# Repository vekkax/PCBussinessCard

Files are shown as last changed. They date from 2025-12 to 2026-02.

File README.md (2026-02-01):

# PCB Business Card

The **PCB Business Card** is a hardware project inspired by the [Hackaday 2024 Business Card Contest](https://hackaday.io/contest/195949-2024-business-card-contest)   and the business cards created by [Salvaged Circuitry](https://www.youtube.com/watch?v=rEdWV4Augfc).

It is a compact and creative way to showcase your capabilities as a hardware designer while sharing your contact details. Beyond being a novelty, the card also functions as a (slightly impractical, but fun) development platform.

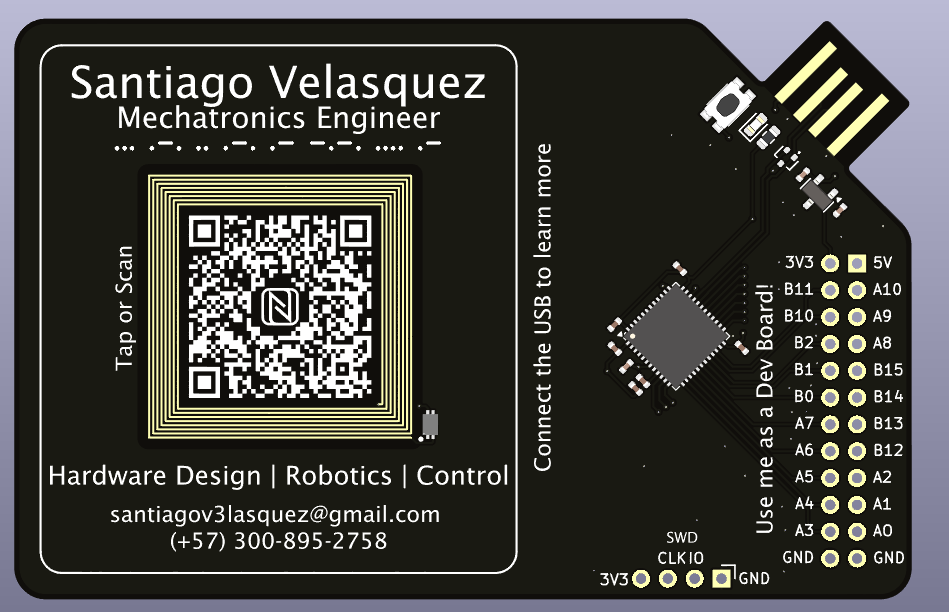
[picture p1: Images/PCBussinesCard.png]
PCB Business Card


---

## Board Design

The PCB was designed using **KiCad**, along with plugins such as **KiKit** and the **Fabrication Toolkit** to generate production-ready files.

The board features:

- **[STM32L452CEU](Datasheets/stm32l452ce.pdf)** microcontroller  
- **[NT2H1311F0DTLH](Datasheets/NTAG213F_216F.pdf)** NFC tag  
- Integrated **PCB USB connector**  
- Optional **pin headers**, allowing the card to be used as a development board  

The USB connector supplies power to the microcontroller through a **[3.3 V LDO regulator](Datasheets/LM3480.pdf)** and includes ESD protection on the data lines using a **TVS diode**. A power LED is placed next to the connector for visual feedback.

The NFC tag is connected to a custom PCB antenna designed using NXP’s [NFC Antenna Design Tool](https://community.nxp.com/t5/NFC/bd-p/nfc).  
This tool provides a convenient interface to design PCB NFC antennas (especially for NXP tags/readers) based on user-defined constraints. ST also provides a similar [antenna design tool](https://eds.st.com/antenna/#/).

---

### Bill of Materials (BOM)

| Reference | Value | Footprint | Quantity |
|---|---|---|---|
| C1–C4, C7–C9 | 100 nF | 0402 | 7 |
| C5 | 10 nF | 0402 | 1 |
| C6 | 1 µF | 0402 | 1 |
| D1 | RCLAMP0582B | SOT-416 | 1 |
| D2 | LED | 0603 | 1 |
| IC1 | NT2H1311F0DTL | SOT1312AB2 | 1 |
| R1 | 120 Ω | 0603 | 1 |
| SW1 | SMD push button | 4.6×1.8×1.9 mm | 1 |
| U1 | STM32L452CEU | QFN-48 | 1 |
| U2 | LM3480-3.3 | SOT-23 | 1 |

> **Note**  
> Reference designators were removed from the PCB layout to improve the visual appearance of the board.

---

## Fabrication

For fabrication, **KiCad’s KiKit** and **JLCPCB’s Fabrication Toolkit** plugins were used.

### Panelization

KiKit was used to panelize the PCB. Each panel contains **four PCB business cards**, separated by mouse bites and surrounded by left and right rails.

The panel configuration file can be found here:  
`PCBussinesCard_Circuit/Panels/panel_config.json`

For more information on KiKit panelization, refer to the official documentation:  
https://yaqwsx.github.io/KiKit/latest/panelization/examples/

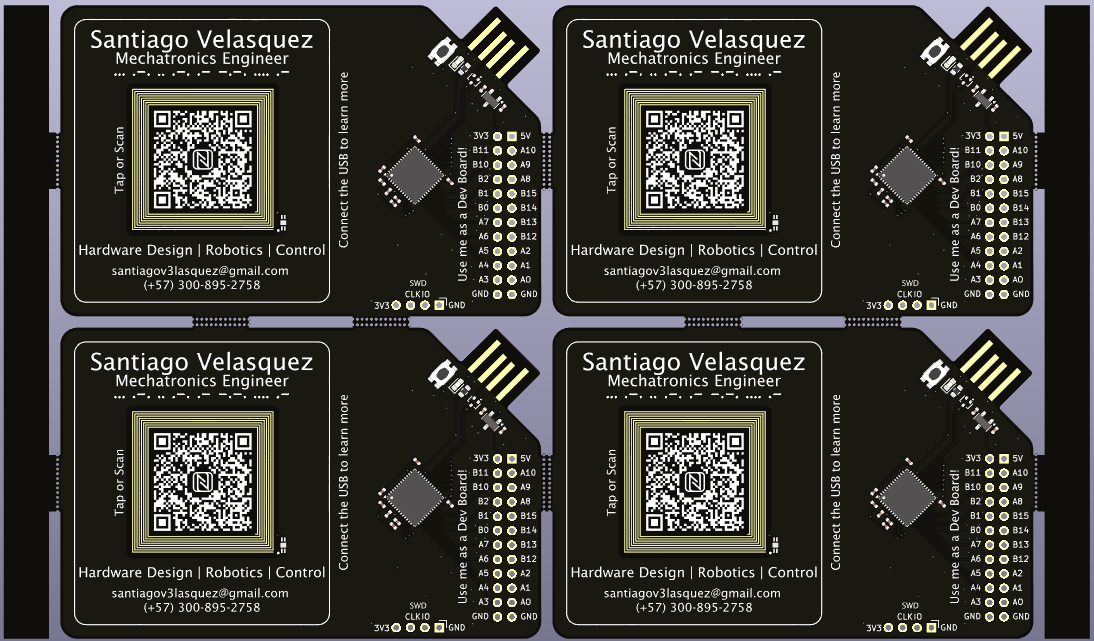
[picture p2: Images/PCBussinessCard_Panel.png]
Panelized Board


### Manufacturing

Manufacturing was done using **JLCPCB**, with production files generated via the JLCPCB Fabrication Toolkit plugin.

---

## Software

The USB connector is used to expose the board as a **USB Mass Storage Device**, allowing a host computer to read and write files (for example, a digital CV) directly to the microcontroller’s internal flash memory.

This implementation uses the STM32’s built-in **USB Full-Speed device** support and the **Mass Storage Class (MSC)**.

The implementation was based on and adapted from the following guide:  
[STM32 USB MSC using Flash Memory – Embetronicx](https://embetronicx.com/tutorials/microcontrollers/stm32/stm32-usb-device-msc-using-flash-memory/)

---

### Flash Memory Configuration

According to the [RM0394 Reference Manual](Datasheets/rm0394-stm32l41xxx42xxx43xxx44xxx45xxx46xxx-advanced-armbased-32bit-mcus-stmicroelectronics.pdf), the STM32L452 has **512 KB of flash memory** organized in a single bank.

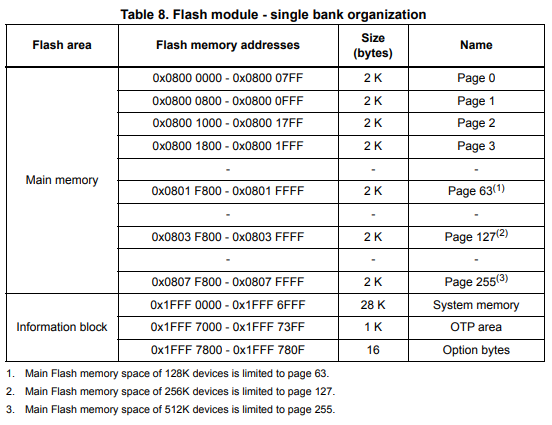
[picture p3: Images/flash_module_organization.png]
Flash memory single bank organization


In this project:
- **64 KB** of flash is reserved for USB mass storage
- Starting at **Page 127**
- Flash start address:  
  **`0x0803F800`**

---

## STM32CubeIDE Configuration

1. Create a new STM32CubeIDE project for the **STM32L452**.
2. Under **Connectivity**, enable **USB Device (FS)**.
3. In **Middleware and Software Packs → USB_DEVICE**:
   - Set the class to **Mass Storage Class**
   - Set `MSC_MEDIA_PACKET` to **32 KB (32768 bytes)**

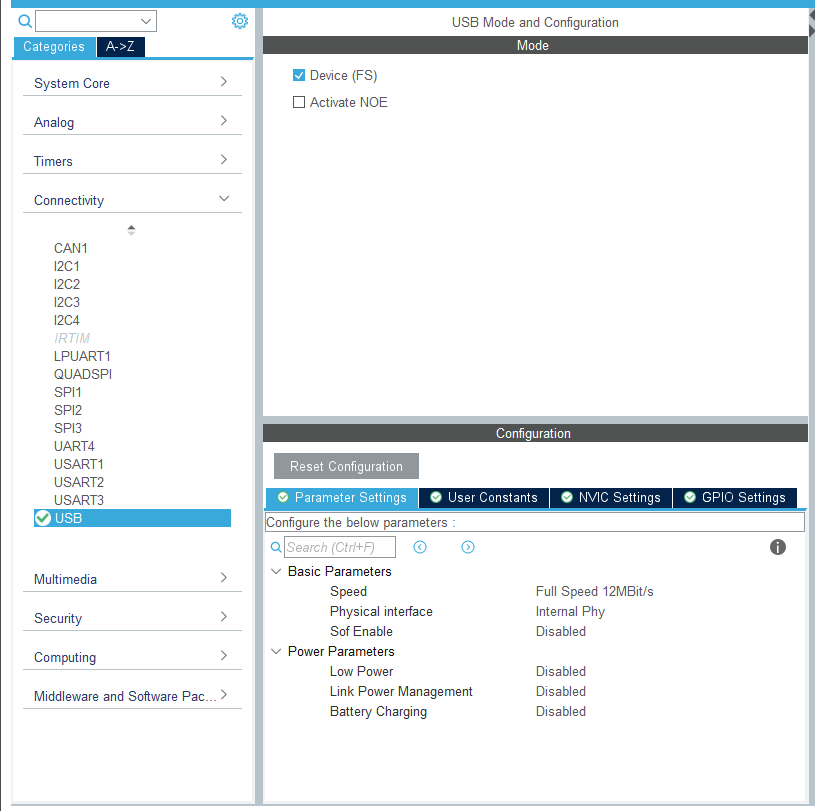
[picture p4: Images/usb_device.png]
USB Device Configuration

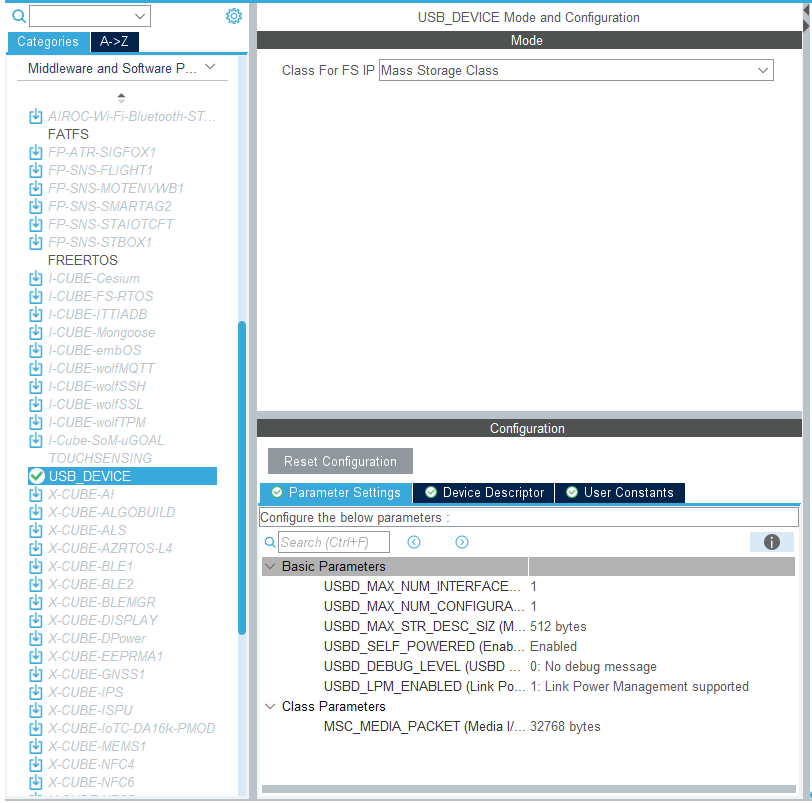
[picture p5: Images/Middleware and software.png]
Middleware Configuration


4. Ensure the USB clock is configured at **48 MHz** in the clock configuration tab.

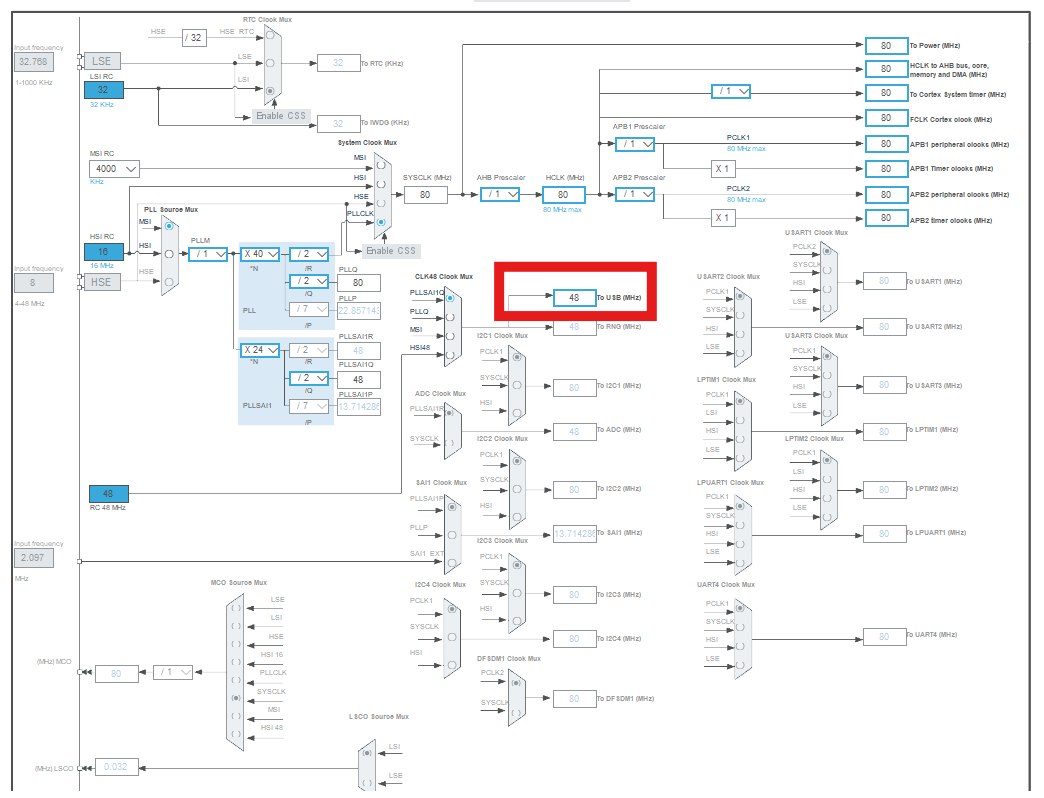
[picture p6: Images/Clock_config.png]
Clock Configuration


5. Generate the project code.

---

## USB Mass Storage Implementation

Open the file: ```usb_device/App/usbd_storage_if.c```

### Storage Parameters

```c
#define STORAGE_LUN_NBR    1
#define STORAGE_BLK_NBR    128      // 128 blocks × 512 bytes = 64 KB
#define STORAGE_BLK_SIZ    0x200    // 512 bytes
```
---
### Flash Write Function
A helper function is added to write data to flash memory:

```c
#include <stdbool.h>

#define USB_FLASH_START_ADDRESS   (  0x0803F800 )    //USB Flash Address (page 127 in STM32L452)
#define TOTAL_USB_DEVICE_SIZE   ( STORAGE_BLK_NBR * STORAGE_BLK_SIZ )

/**
  * @brief  Writes data into the FLASH.
  * @param  buf: data buffer.
  * @param  blk_addr: Logical block address.
  * @param  blk_len: Blocks number.
  * @retval HAL_StatusTypeDef
  */
static HAL_StatusTypeDef write_data_to_flash( uint8_t *buf, uint32_t blk_addr, uint16_t blk_len )
{
  HAL_StatusTypeDef ret = HAL_OK;
  uint8_t           data[ TOTAL_USB_DEVICE_SIZE ];

  do
  {
    /* First copy the data to the local buffer from Flash */
    memcpy( data, (const void *)USB_FLASH_START_ADDRESS, TOTAL_USB_DEVICE_SIZE );
    
    /* Make modifications in the local buffer */
    memcpy((void*)&data[blk_addr*STORAGE_BLK_SIZ], buf, (blk_len*STORAGE_BLK_SIZ));
    
    ret = HAL_FLASH_Unlock();
    if( ret != HAL_OK )
    {
      break;
    }
    
    /* Erase the Flash */
    FLASH_EraseInitTypeDef EraseInitStruct;
    uint32_t SectorError;
    EraseInitStruct.TypeErase     = FLASH_TYPEERASE_SECTORS;
    EraseInitStruct.Sector        = FLASH_SECTOR_6;
    EraseInitStruct.NbSectors     = 1;                    //erase 1 sector(6)
    EraseInitStruct.VoltageRange  = FLASH_VOLTAGE_RANGE_3;
    
    ret = HAL_FLASHEx_Erase( &EraseInitStruct, &SectorError );
    
    /* Write the data to the Flash */
    for( uint32_t i = 0; i < TOTAL_USB_DEVICE_SIZE; i++)
    {
      ret = HAL_FLASH_Program( FLASH_TYPEPROGRAM_BYTE,
                  ( USB_FLASH_START_ADDRESS + i ),
                  data[i]
                  );
    
      if( ret != HAL_OK )
      {
        break;
      }
    }
    
    HAL_FLASH_Lock();
  } while( false );

  return( ret );
}
```
The function:

1. Copies existing flash contents to a RAM buffer

2. Modifies the buffer with new data

3. Erases the corresponding flash sector

4. Writes the updated data back to flash

---
### Write Callback
```c
int8_t STORAGE_Write_FS(uint8_t lun, uint8_t *buf, uint32_t blk_addr, uint16_t blk_len)
{
  UNUSED(lun);
  return write_data_to_flash(buf, blk_addr, blk_len);
}

```
---
### Read Callback
Reading data is simpler and can be done directly from flash:

```c
int8_t STORAGE_Read_FS(uint8_t lun, uint8_t *buf, uint32_t blk_addr, uint16_t blk_len)
{
  UNUSED(lun);
  memcpy(
    buf,
    (const void *)(USB_FLASH_START_ADDRESS + (blk_addr * STORAGE_BLK_SIZ)),
    blk_len * STORAGE_BLK_SIZ
  );
  return USBD_OK;
}

```
---
### Usage
1. Flash the firmware to the board.

2. Connect the PCB Business Card via USB.

3. A removable USB drive will appear.

4. Format the drive if prompted.

5. Files can now be read from and written to the device.

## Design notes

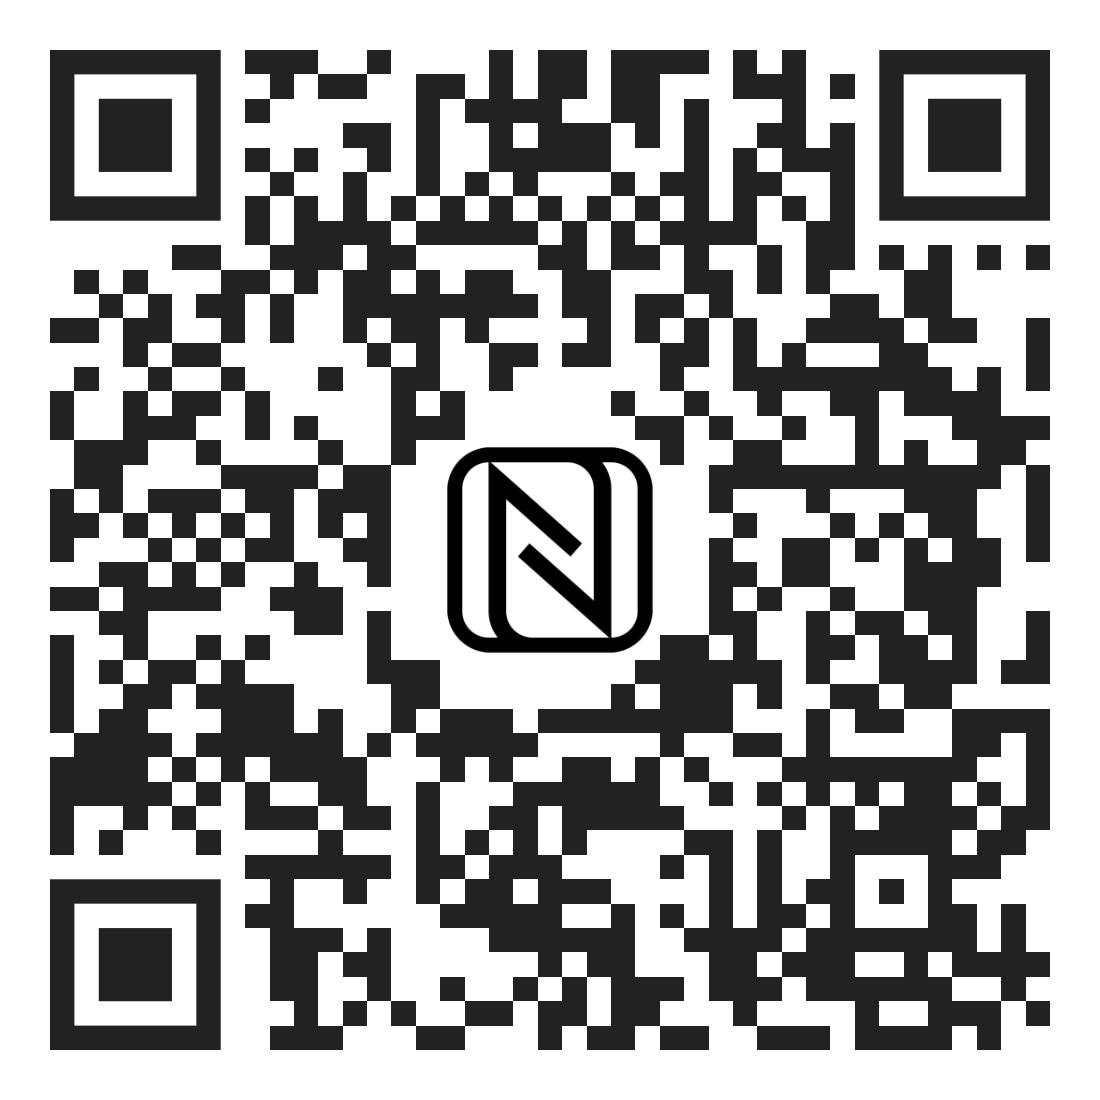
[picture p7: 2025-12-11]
PCBussinesCard_Circuit/Images/QR_NFC.png

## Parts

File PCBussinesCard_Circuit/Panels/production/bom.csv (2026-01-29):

Designator | Footprint | Quantity | Value | LCSC Part #
0201_4, 0201_3, 0201_2, 0201 | 0201 | 4 | C_0201_0603Metric
0402_4, 0402_3, 0402_2, 0402 | 0402 | 4 | R_0402_1005Metric
0603_4, 0603_3, 0603_2, 0603 | 0603 | 4 | R_0603_1608Metric
0805_4, 0805_3, 0805_2, 0805 | 0805 | 4 | R_0805_2012Metric
1206_4, 1206_3, 1206_2, 1206 | 1206 | 4 | R_1206_3216Metric
1812_4, 1812_3, 1812_2, 1812 | 1812 | 4 | R_1812_4532Metric
2010_4, 2010_3, 2010_2, 2010 | 2010 | 4 | R_2010_5025Metric_Pad1.40x2.65mm_HandSolder
2512_4, 2512_3, 2512_2, 2512 | 2512 | 4 | R_2512_6332Metric
2816_4, 2816_3, 2816_2, 2816 | 2816 | 4 | R_2816_7142Metric
4020_4, 4020_3, 4020_2, 4020 | 4020 | 4 | R_4020_10251Metric
C1_4, C1_3, C1_2, C1, C2_4, C2_3, C2_2, C2, C3_4, C3_3, C3_2, C3, C4_4, C4_3, C4_2, C4, C7_4, C7_3, C7_2, C7, C8_4, C8_3, C8_2, C8, C9_4, C9_3, C9_2, C9 | 0402 | 28 | 100nF
C5_4, C5_3, C5_2, C5 | 0402 | 4 | 10nF
C6_4, C6_3, C6_2, C6 | 0402 | 4 | 1uF
D1_4, D1_3, D1_2, D1 | SOT-416 | 4 | RCLAMP0582B
D2_4, D2_3, D2_2, D2 | 0603 | 4 | LED
IC1_4, IC1_3, IC1_2, IC1 | SON50P200X150X50-5N | 4 | NT2H1311F0DTL
J1_4, J1_3, J1_2, J1 | PinHeader_1x04_P2.54mm_Horizontal | 4 | Conn_01x04_Pin
J2_4, J2_3, J2_2, J2 | PCB_USB_A | 4 | USB_A_PCB
J3_4, J3_3, J3_2, J3 | PinSocket_2x12_P2.54mm_Vertical | 4 | Conn_02x12_Odd_Even
LQFP-32 0.5_4, LQFP-32 0.5_3, LQFP-32 0.5_2, LQFP-32 0.5 | LQFP-32_5x5mm_P0.5mm | 4 | LQFP-32_5x5mm_P0.5mm
LQFP-32 0.8_4, LQFP-32 0.8_3, LQFP-32 0.8_2, LQFP-32 0.8 | LQFP-32_7x7mm_P0.8mm | 4 | LQFP-32_7x7mm_P0.8mm
QFN-16_4, QFN-16_3, QFN-16_2, QFN-16 | QFN-16-1EP_3x3mm_P0.5mm_EP1.7x1.7mm | 4 | QFN-16-1EP_3x3mm_P0.5mm_EP1.7x1.7mm
QFN-32 _4, QFN-32 _3, QFN-32 _2, QFN-32 | QFN-32-1EP_4x4mm_P0.4mm_EP2.9x2.9mm | 4 | QFN-32-1EP_4x4mm_P0.4mm_EP2.9x2.9mm
R1_4, R1_3, R1_2, R1 | 0603 | 4 | 120R
SOT-223_4, SOT-223_3, SOT-223_2, SOT-223 | SOT-223 | 4 | SOT-223
SOT-23-3_4, SOT-23-3_3, SOT-23-3_2, SOT-23-3 | SOT-23-3 | 4 | SOT-23-3
SOT-23-5_4, SOT-23-5_3, SOT-23-5_2, SOT-23-5 | SOT-23-5 | 4 | SOT-23-5
SW1_4, SW1_3, SW1_2, SW1 | Push_SMD_4.6x2.8mm_h1.9mm | 4 | SMD_4.6x2.8mm_h1.9mm
TSSOP-16_4, TSSOP-16_3, TSSOP-16_2, TSSOP-16 | TSSOP-16-1EP_4.4x5mm_P0.65mm_EP3x3mm | 4 | TSSOP-16-1EP_4.4x5mm_P0.65mm_EP3x3mm
TSSOP-24_4, TSSOP-24_3, TSSOP-24_2, TSSOP-24 | TSSOP-24-1EP_4.4x7.8mm_P0.65mm_EP3.2x5mm | 4 | TSSOP-24-1EP_4.4x7.8mm_P0.65mm_EP3.2x5mm
U2_4, U2_3, U2_2, U2 | QFN-48-1EP_7x7mm_P0.5mm_EP5.6x5.6mm | 4 | STM32L452CEUx
U3_4, U3_3, U3_2, U3 | SOT-23 | 4 | LM3480-3.3

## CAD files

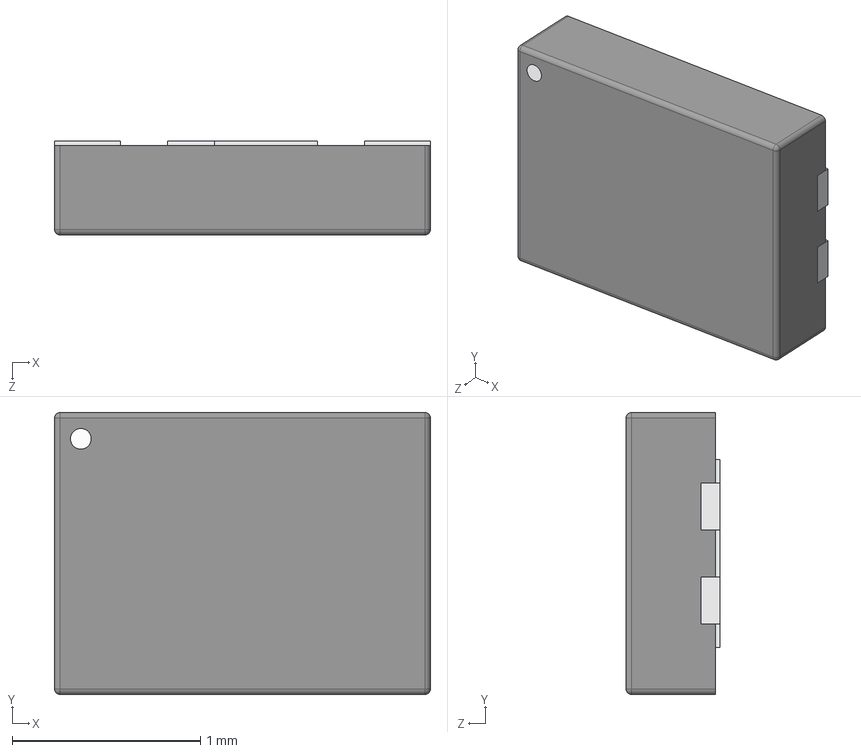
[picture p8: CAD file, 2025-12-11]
PCBussinesCard_Circuit/Imports/NT2H1311F0DTL/3D/NT2H1311F0DTL.stp
2.00 x 1.50 x 0.5 mm

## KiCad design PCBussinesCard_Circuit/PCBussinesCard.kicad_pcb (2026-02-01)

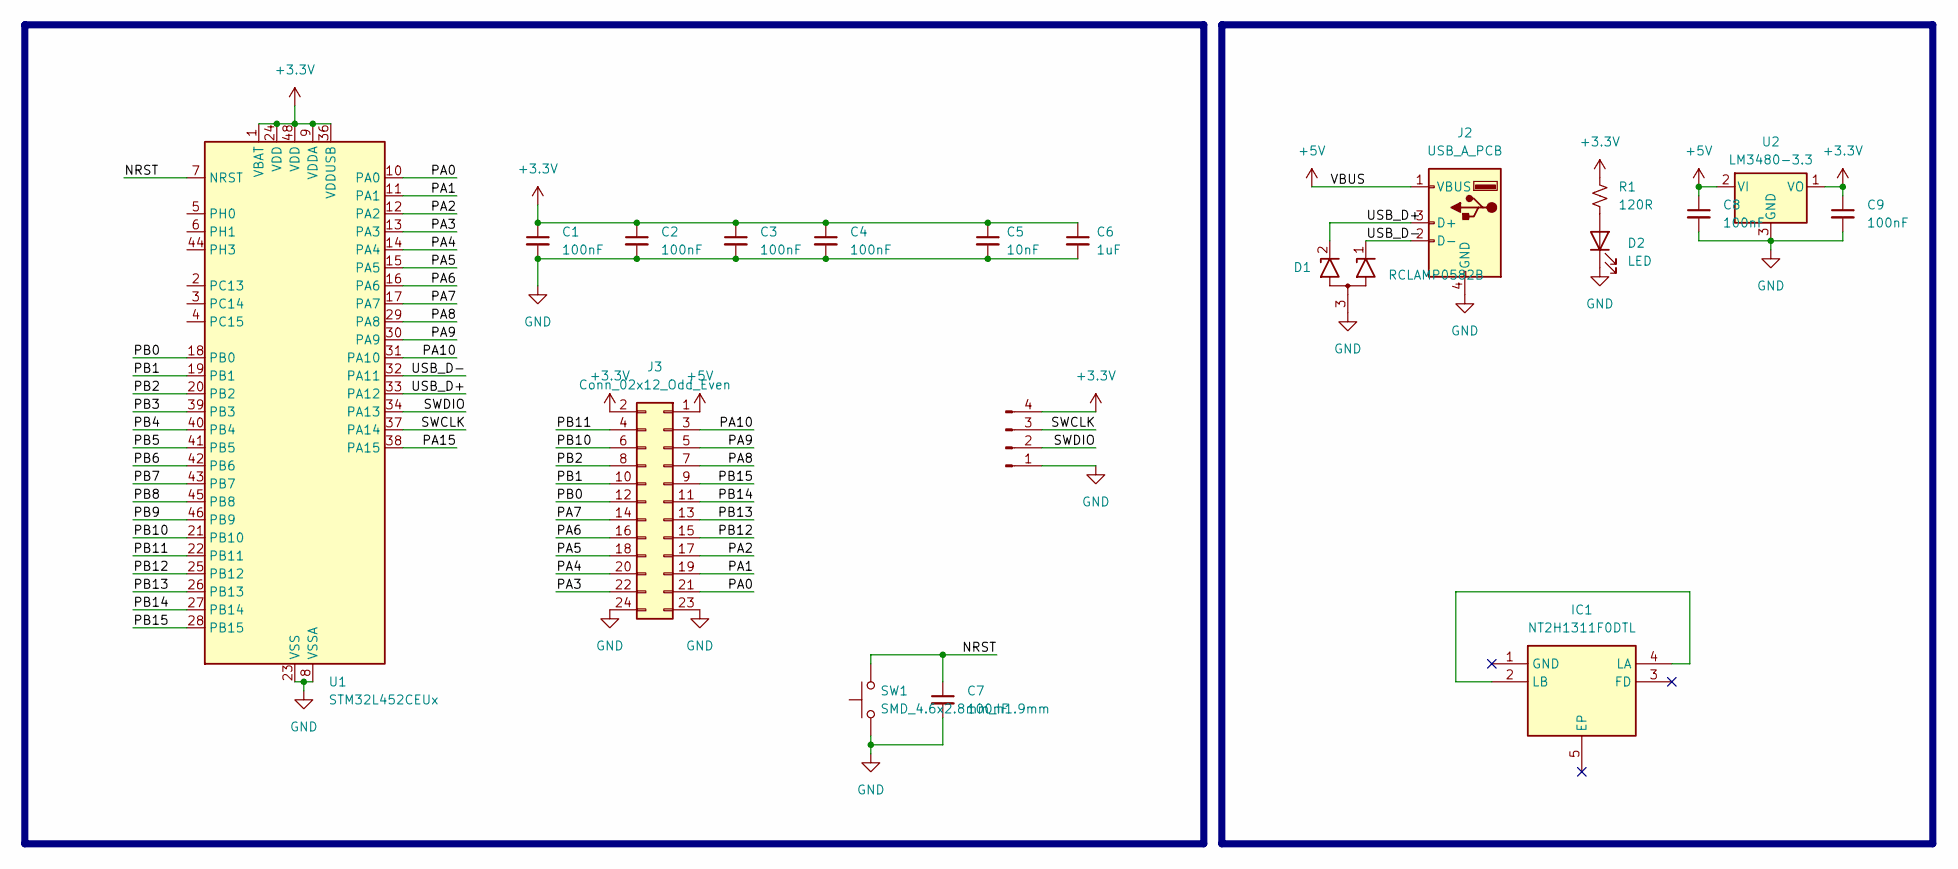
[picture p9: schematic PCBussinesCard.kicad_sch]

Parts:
C1, C2, C3, C4, C7, C8, C9: 100nF; C_0402_1005Metric
C5: 10nF; C_0402_1005Metric
C6: 1uF; C_0402_1005Metric
D1: RCLAMP0582B; SOT-416
D2: LED; LED_0603_1608Metric
IC1: NT2H1311F0DTL; SON50P200X150X50-5N; Manufacturer_Part_Number NT2H1311F0DTL
J1: Conn_01x04_Pin; PinHeader_1x04_P2.54mm_Horizontal
J2: USB_A_PCB; PCB_USB_A
J3: Conn_02x12_Odd_Even; PinSocket_2x12_P2.54mm_Vertical
R1: 120R; R_0603_1608Metric
SW1: SMD_4.6x2.8mm_h1.9mm; Push_SMD_4.6x2.8mm_h1.9mm
U1: STM32L452CEUx; QFN-48-1EP_7x7mm_P0.5mm_EP5.6x5.6mm
U2: LM3480-3.3; SOT-23

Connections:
+3.3V: C1.1, C2.1, C3.1, C4.1, C5.1, C6.1, C9.1, J1.4, J3.2, R1.1, U1.1 (VBAT), U1.9 (VDDA), U1.24 (VDD), U1.36 (VDDUSB), U1.48 (VDD), U2.1 (VO)
+5V: C8.1, J2.1 (VBUS), J3.1, U2.2 (VI)
/NRST: C7.1, SW1.2, U1.7 (NRST)
/PA0: J3.21, U1.10 (PA0)
/PA1: J3.19, U1.11 (PA1)
/PA2: J3.17, U1.12 (PA2)
/PA3: J3.22, U1.13 (PA3)
/PA4: J3.20, U1.14 (PA4)
/PA5: J3.18, U1.15 (PA5)
/PA6: J3.16, U1.16 (PA6)
/PA7: J3.14, U1.17 (PA7)
/PA8: J3.7, U1.29 (PA8)
/PA9: J3.5, U1.30 (PA9)
/PA10: J3.3, U1.31 (PA10)
/PA15: U1.38 (PA15)
/PB0: J3.12, U1.18 (PB0)
/PB1: J3.10, U1.19 (PB1)
/PB2: J3.8, U1.20 (PB2)
/PB3: U1.39 (PB3)
/PB4: U1.40 (PB4)
/PB5: U1.41 (PB5)
/PB6: U1.42 (PB6)
/PB7: U1.43 (PB7)
/PB8: U1.45 (PB8)
/PB9: U1.46 (PB9)
/PB10: J3.6, U1.21 (PB10)
/PB11: J3.4, U1.22 (PB11)
/PB12: J3.15, U1.25 (PB12)
/PB13: J3.13, U1.26 (PB13)
/PB14: J3.11, U1.27 (PB14)
/PB15: J3.9, U1.28 (PB15)
/SWCLK: J1.3, U1.37 (PA14)
/SWDIO: J1.2, U1.34 (PA13)
/USB_D+: D1.2 (K2), J2.3 (D+), U1.33 (PA12)
/USB_D-: D1.1 (K1), J2.2 (D-), U1.32 (PA11)
GND: C1.2, C2.2, C3.2, C4.2, C5.2, C6.2, C7.2, C8.2, C9.2, D1.3 (A), D2.1 (K), J1.1, J2.4 (GND), J3.23, J3.24, SW1.1, U1.8 (VSSA), U1.23 (VSS), U1.35 (VSS), U1.47 (VSS), U1.49 (VSS), U2.3 (GND)
unnamed: D2.2 (A), R1.2
unnamed: IC1.2 (LB), IC1.4 (LA)

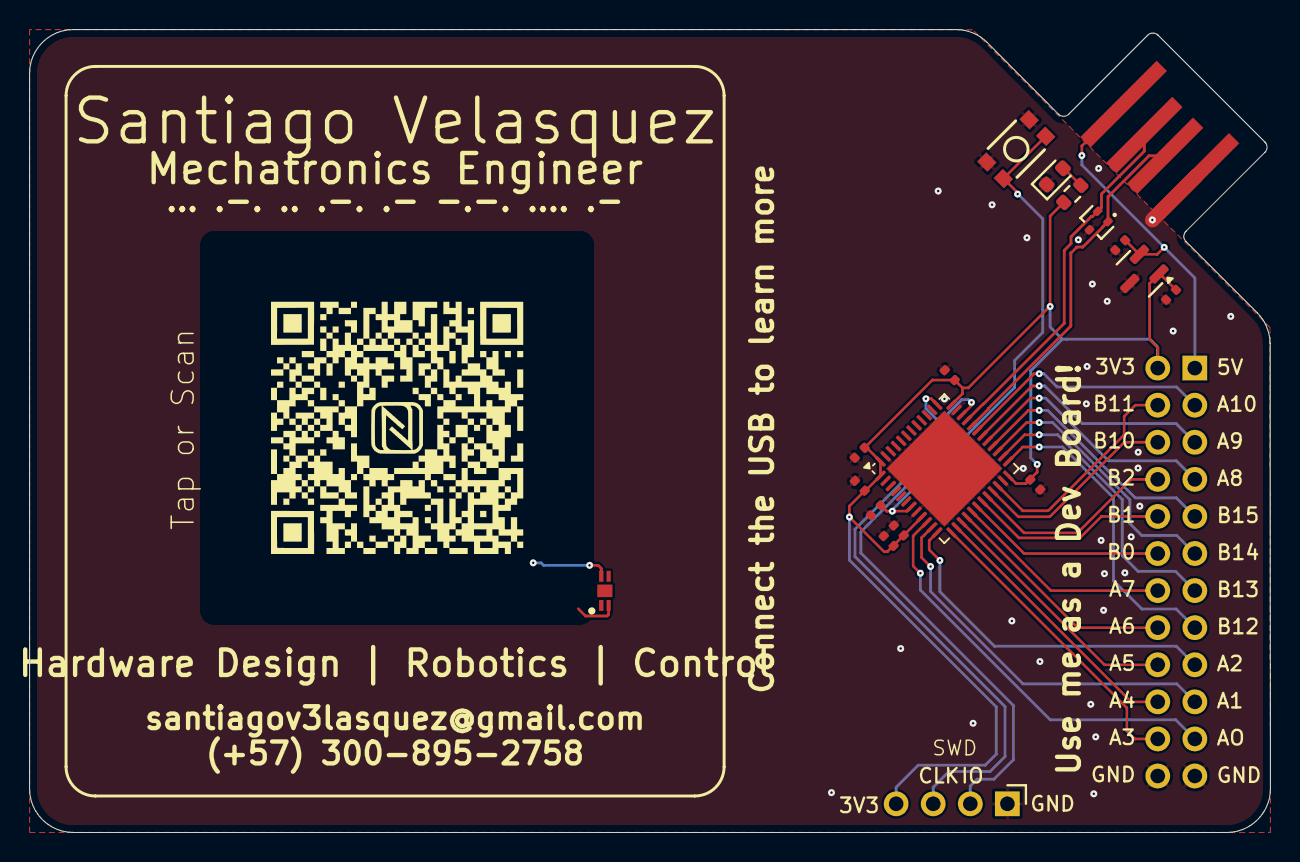
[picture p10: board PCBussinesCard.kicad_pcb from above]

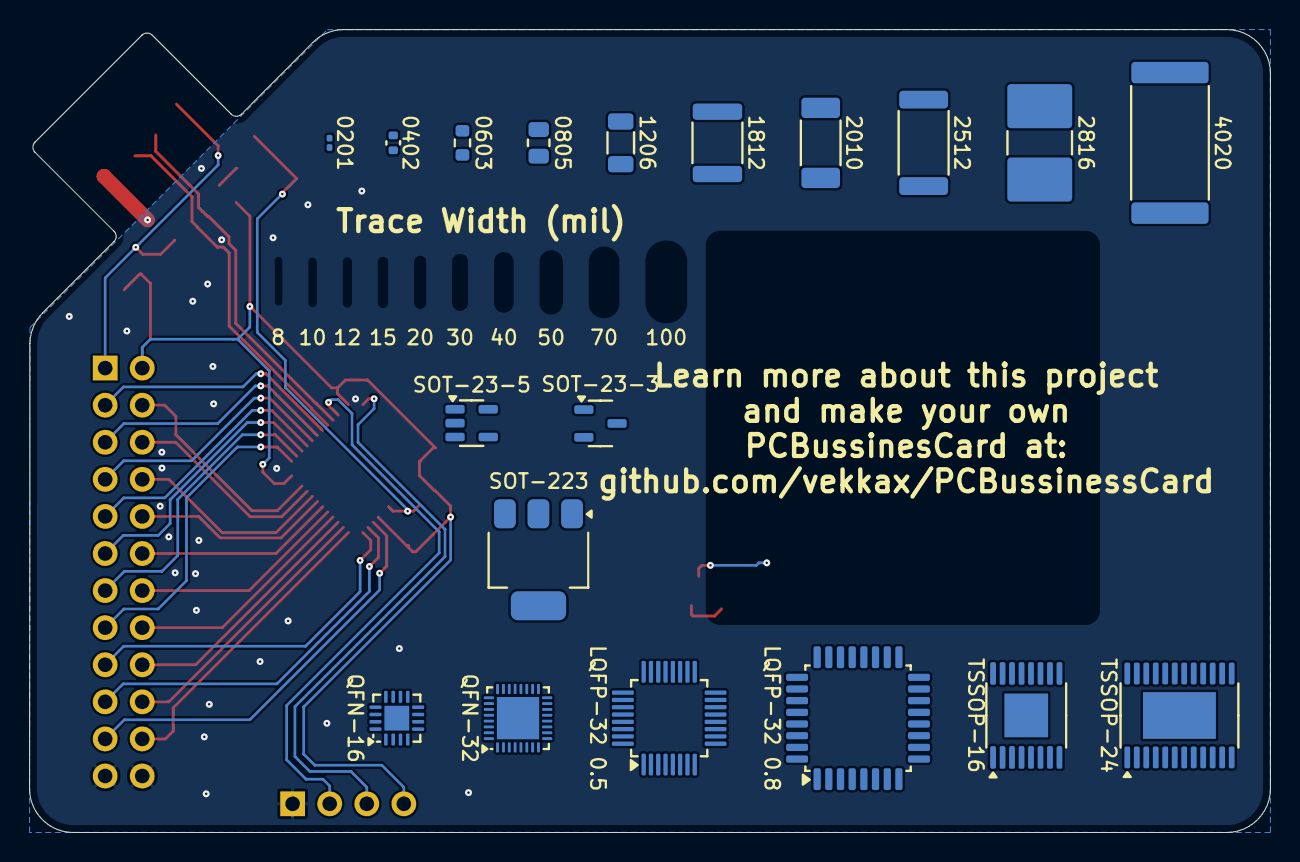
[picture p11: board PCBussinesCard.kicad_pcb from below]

Board: 2 copper layers, 85.0 x 55.0 mm, 38 parts (19 on the bottom side), 30 nets.

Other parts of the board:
0201: C_0201_0603Metric
0402: R_0402_1005Metric
0603: R_0603_1608Metric
0805: R_0805_2012Metric
1206: R_1206_3216Metric
1812: R_1812_4532Metric
2010: R_2010_5025Metric_Pad1.40x2.65mm_HandSolder
2512: R_2512_6332Metric
2816: R_2816_7142Metric
4020: R_4020_10251Metric
LQFP-32 0.5: LQFP-32_5x5mm_P0.5mm
LQFP-32 0.8: LQFP-32_7x7mm_P0.8mm
QFN-16: QFN-16-1EP_3x3mm_P0.5mm_EP1.7x1.7mm
QFN-32 : QFN-32-1EP_4x4mm_P0.4mm_EP2.9x2.9mm
SOT-23-3: SOT-23-3
SOT-23-5: SOT-23-5
SOT-223: SOT-223
TSSOP-16: TSSOP-16-1EP_4.4x5mm_P0.65mm_EP3x3mm
TSSOP-24: TSSOP-24-1EP_4.4x7.8mm_P0.65mm_EP3.2x5mm

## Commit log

2025-12-07 Schematic and layout sketch
    [PCBussinesCard.kicad_pcb, PCBussinesCard.kicad_sch]
2025-12-11 provisional antena added
    [NT2H1311F0DTL.stp]
2025-12-11 cleanup and reorganizing
    [PCBussinesCard.kicad_pcb, PCBussinesCard.kicad_sch]
2026-01-23 Version 1.0
    [PCBussinesCard.kicad_pcb, PCBussinesCard.kicad_sch]
2026-01-29 Production V1.0
    [PCBussinesCard.kicad_pcb, PCBussinesCard.kicad_sch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]
2026-01-29 Production Panels V1.0
    [PCBussinesCard_panel.kicad_pcb]
2026-02-01 README added and unnecesary files removed
    [PCBussinesCard.kicad_pcb, PCBussinesCard.kicad_sch, bom.csv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]
